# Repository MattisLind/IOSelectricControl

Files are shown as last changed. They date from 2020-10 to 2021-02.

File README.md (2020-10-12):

# IOSelectricControl
This project is to create a modern interface to an old IBM 731 IO Selectric terminal.

Back in the mid seventies my father bought a IO Selectric to use with his homebuilt computer. In order to connect it over serial line he had to build a small box with interface electronics. But he also did massive amounts of modifications to the 731 itself.

Top view. Quite a lot of dirt.

Top view when project started

Bottom view show all the modifications. There is even a power supply built into it

Bottom view

Unfortunately the documentation that covered what was done back then was scarce so I decvided to remove the modifications and get it back to a more original state. Instead of the control box full of TTL circuits and relays I decided to build a circuit based on a STM32 microcontroller to be able to have it to talk over USB.

## Links

* [Selectric I/O Reference Manual - Section 1](http://bitsavers.org/pdf/ibm/typewriter/selectric/241-5308_IO_SelectricRefMan.pdf)
* [Field Engineering Maintenance Manual Selectric ® I/O Keyboard Printer](http://bitsavers.org/pdf/ibm/typewriter/selectric/S225-1726-7_IOseleMnt_Nov70.pdf)

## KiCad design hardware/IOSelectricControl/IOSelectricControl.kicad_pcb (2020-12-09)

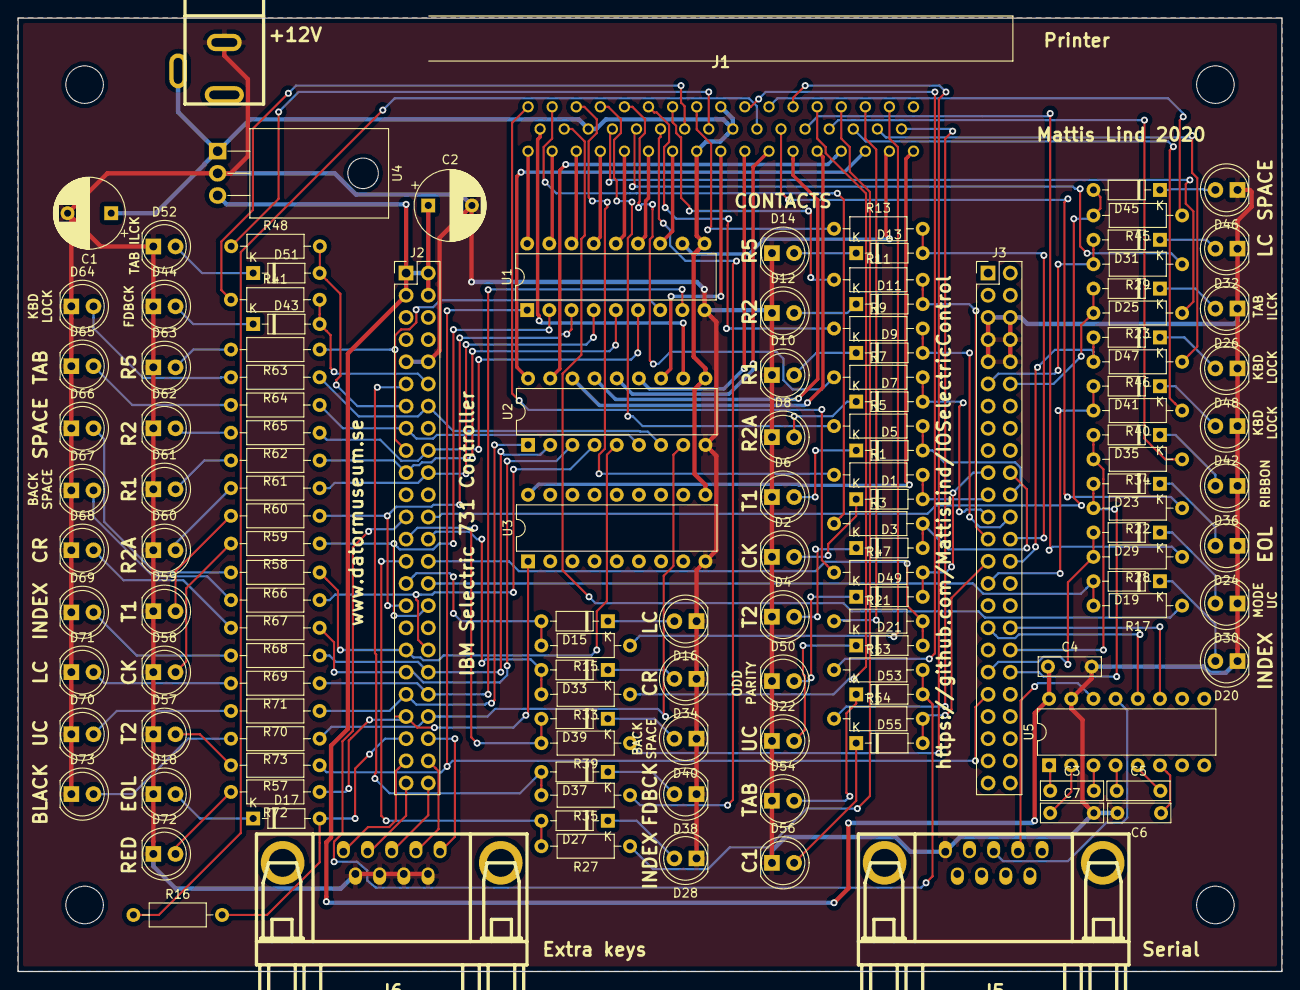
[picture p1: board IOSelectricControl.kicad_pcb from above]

Board: 2 copper layers, 144.8 x 109.2 mm, 136 parts (0 on the bottom side), 153 nets.

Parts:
C1: 47u; CP_Radial_D8.0mm_P5.00mm
C2: 100u; CP_Radial_D8.0mm_P5.00mm
C3, C4, C5, C6, C7: 0.1u; C_Rect_L7.0mm_W2.0mm_P5.00mm
D1, D3, D5, D7, D9, D11, D13, D15, D17, D19, D21, D23, D25, D27, D29, D31, D33, D35, D37, D39, D41, D43, D45, D47, D49, D51, D53, D55: 1N4148; D_DO-35_SOD27_P7.62mm_Horizontal
D2, D4, D6, D8, D10, D12, D14, D36, D50: YEL; LED_D5.0mm
D16, D22, D28, D34, D40, D46, D54: AMB; LED_D5.0mm
D18, D20, D26, D32, D44, D48: RED; LED_D5.0mm
D24, D30, D38, D42, D52, D56: GRN; LED_D5.0mm
D57, D58, D59, D60, D61, D62, D63: BLU; LED_D5.0mm
D64, D65, D66, D67, D68, D69, D70, D71, D72, D73: ORA; LED_D5.0mm
J1: DB-50; DD50S564TLF
J2, J3: HEADER_24x2; PinHeader_2x24_P2.54mm_Vertical
J4: +12V; dc_socket
J5: Serial; DB_9F
J6: Extra keys; DB_9F
R1, R3, R5, R7, R9, R11, R13, R15, R16, R17, R21, R22, R23, R27, R28, R29, R33, R34, R35, R39, R40, R41, R45, R46, R47, R48, R53, R54: 4,7k; R_Axial_DIN0207_L6.3mm_D2.5mm_P10.16mm_Horizontal
R57, R58, R59, R60, R61, R62, R63, R64, R65, R66, R67, R68, R69, R70, R71, R72, R73: 470; R_Axial_DIN0207_L6.3mm_D2.5mm_P10.16mm_Horizontal
U1, U2, U3: ULN2803A; DIP-18_W7.62mm
U4: L7805; TO-220-3_Horizontal_TabDown
U5: MAX202; DIP-16_W7.62mm

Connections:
+5V: C2.1, C4.1, J2.1, J2.2, J2.3, J2.4, U4.3, U5.16
+12V: C1.1, J1.8, J1.20, J1.26, J1.42, J4.1, U1.10, U2.10, U3.10, U4.1
/A: J1.1, U1.18
/AA: J1.44, R45.1
/B: J1.2, U1.17
/BB: J1.45, R39.1
/BREAK: J2.44, J6.1
/C: J1.3, U1.16
/CC: J1.46, R33.1
/CON_C1_NC: J1.19, R17.1
/CON_C1_NO: J1.33, R54.1
/CON_CK_NO: J1.36, R1.1
/CON_EOL_NC: J1.27, R16.1
/CON_EOL_NO: J1.28, R22.1
/CON_FDBCK_NC: J1.23, R35.1
/CON_FDBCK_NO: J1.24, R41.1
/CON_INDEX_NO: J1.47, R27.1
/CON_KBD_NC: J1.31, R40.1
/CON_KBD_NO: J1.32, R46.1
/CON_LC_NO: J1.49, R15.1
/CON_MODE_LC_NC: J1.22, R29.1
/CON_MODE_UC_NO: J1.29, R28.1
/CON_ODD_PARITY: J1.34, R47.1
/CON_R1_NO: J1.39, R9.1
/CON_R2A_NO: J1.38, R7.1
/CON_R2_NO: J1.40, R11.1
/CON_R5_NO: J1.41, R13.1
/CON_RIBBON_NO: J1.30, R34.1
/CON_T1_NO: J1.37, R5.1
/CON_T2_NO: J1.35, R3.1
/CON_TAB_ILCK_NC: J1.21, R23.1
/CON_TAB_ILCK_NO: J1.25, R48.1
/CON_TAB_NO: J1.43, R53.1
/CON_UC_NO: J1.48, R21.1
/CTRL: J2.46, J6.2
/D: J1.4, U1.15
/E: J1.5, U1.14
/EIA_RX: J5.3, U5.13
/EIA_TX: J5.2, U5.14
/F: J1.6, U1.13
/H: J1.7, U1.12
/K: J1.9, U2.12
/L: J1.10, U2.13
/M: J1.11, U2.14
/N: J1.12, U2.15
/P: J1.13, U2.16
/PAR0: J2.47, J6.4
/PAR1: J2.48, J6.3
/PARODD: J2.45, J6.5
/R: J1.14, U2.17
/S: J1.15, U2.18
/SER_RX: J3.33, U5.12
/SER_TX: J3.34, U5.11
/SOL_BLACK: J1.18, U2.11
/SOL_LC: J1.16, U1.11
/SOL_RED: J1.17, U3.18
/STM_BLACK: J2.42, R73.1, U2.8
/STM_BSP: J2.36, R67.1, U2.4
/STM_BSP_NO: D39.2, J2.25, R39.2
/STM_C1_NC: D19.2, J2.30, R17.2
/STM_C1_NO: D55.2, J3.27, R54.2
/STM_CK: J2.32, R58.1, U1.2
/STM_CK_NO: D1.2, J3.21, R1.2
/STM_CR: J2.37, R68.1, U2.3
/STM_CR_NO: D33.2, J2.26, R33.2
/STM_EOL_NC: D17.2, J2.43, R16.2
/STM_EOL_NO: D23.2, J3.38, R22.2
/STM_FDBCK_NC: D37.2, J2.11, R35.2
/STM_FDBCK_NO: D43.2, J2.12, R41.2
/STM_INDEX: J2.38, R69.1, U2.2
/STM_INDEX_NO: D27.2, J2.27, R27.2
/STM_KBD_LOCK: J2.14, R64.1, U2.7
/STM_KBD_NC: D41.2, J3.29, R40.2
/STM_KBD_NO: D47.2, J3.28, R46.2
/STM_LC: J2.40, R71.1, U1.8
/STM_LC_NO: D15.2, J2.29, R15.2
/STM_MODE_LC_NC: D31.2, J3.11, R29.2
/STM_MODE_UC_NO: D29.2, J3.37, R28.2
/STM_ODD_PAR_NO: D49.2, J3.19, R47.2
/STM_R1: J2.19, R61.1, U1.5
/STM_R1_NO: D9.2, J3.24, R9.2
/STM_R2: J2.18, R62.1, U1.6
/STM_R2A: J2.20, R60.1, U1.4
/STM_R2A_NO: D7.2, J3.23, R7.2
/STM_R2_NO: D11.2, J3.25, R11.2
/STM_R5: J2.17, R63.1, U1.7
/STM_R5_NO: D13.2, J3.26, R13.2
/STM_RED: J2.41, R72.1, U3.1
/STM_RIBBON_NO: D35.2, J3.36, R34.2
/STM_SP: J2.35, R66.1, U2.5
/STM_SP_NO: D45.2, J2.24, R45.2
/STM_T1: J2.31, R59.1, U1.3
/STM_T1_NO: D5.2, J3.22, R5.2
/STM_T2: J3.39, R57.1, U1.1
/STM_T2_NO: D3.2, J3.20, R3.2
/STM_TAB: J2.15, R65.1, U2.6
/STM_TAB_ILCK_NC: D25.2, J3.12, R23.2
/STM_TAB_ILCK_NO: D51.2, J2.13, R48.2
/STM_TAB_NO: D53.2, J2.23, R53.2
/STM_UC: J2.39, R70.1, U2.1
/STM_UC_NO: D21.2, J2.28, R21.2
GND: C1.2, C2.2, C4.2, C6.2, C7.2, D2.1, D4.1, D6.1, D8.1, D10.1, D12.1, D14.1, D16.1, D18.1, D20.1, D22.1, D24.1, D26.1, D28.1, D30.1, D32.1, D34.1, D36.1, D38.1, D40.1, D42.1, D44.1, D46.1, D48.1, D50.1, D52.1, D54.1, D56.1, D57.1, D58.1, D59.1, D60.1, D61.1, D62.1, D63.1, D64.1, D65.1, D66.1, D67.1, D68.1, D69.1, D70.1, D71.1, D72.1, D73.1, J2.9, J2.10, J3.5, J3.6, J3.7, J3.8, J3.9, J3.10, J4.2, J5.5, J6.6, J6.7, J6.8, J6.9, U1.9, U2.9, U3.9, U4.2, U5.15
unnamed: C3.1, U5.1
unnamed: C3.2, U5.3
unnamed: C5.1, U5.4
unnamed: C5.2, U5.5
unnamed: C6.1, U5.6
unnamed: C7.1, U5.2
unnamed: D1.1, D2.2
unnamed: D3.1, D4.2
unnamed: D5.1, D6.2
unnamed: D7.1, D8.2
unnamed: D9.1, D10.2
unnamed: D11.1, D12.2
unnamed: D13.1, D14.2
unnamed: D15.1, D16.2
unnamed: D17.1, D18.2
unnamed: D19.1, D20.2
unnamed: D21.1, D22.2
unnamed: D23.1, D24.2
unnamed: D25.1, D26.2
unnamed: D27.1, D28.2
unnamed: D29.1, D30.2
unnamed: D31.1, D32.2
unnamed: D33.1, D34.2
unnamed: D35.1, D36.2
unnamed: D37.1, D38.2
unnamed: D39.1, D40.2
unnamed: D41.1, D42.2
unnamed: D43.1, D44.2
unnamed: D45.1, D46.2
unnamed: D47.1, D48.2
unnamed: D49.1, D50.2
unnamed: D51.1, D52.2
unnamed: D53.1, D54.2
unnamed: D55.1, D56.2
unnamed: D57.2, R57.2
unnamed: D58.2, R58.2
unnamed: D59.2, R59.2
unnamed: D60.2, R60.2
unnamed: D61.2, R61.2
unnamed: D62.2, R62.2
unnamed: D63.2, R63.2
unnamed: D64.2, R64.2
unnamed: D65.2, R65.2
unnamed: D66.2, R66.2
unnamed: D67.2, R67.2
unnamed: D68.2, R68.2
unnamed: D69.2, R69.2
unnamed: D70.2, R70.2
unnamed: D71.2, R71.2
unnamed: D72.2, R72.2
unnamed: D73.2, R73.2

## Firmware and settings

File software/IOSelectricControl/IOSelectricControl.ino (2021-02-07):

/*
  IOSelectricControl

  STM32duino.com  Generic STMF103C Series  / STM32F103C8 20 k RAM 64 k flash ST-link

*/
#define CC_NUL 0
#define CC_R5  1 << 0
#define CC_R2  1 << 1
#define CC_R1  1 << 2
#define CC_R2A 1 << 3
#define CC_T1  1 << 4
#define CC_CK  1 << 5
#define CC_T2  1 << 6
#define CC_UC  1 << 7
#define CC_INDEX 1 << 8
#define CC_CR 1 << 9
#define CC_BSP 1 << 10
#define CC_SP  1 << 11
#define CC_TAB 1 << 12

int asciiToCorrespondanceCode [] = {
  CC_NUL,  // NUL
  CC_NUL,  // SOH
  CC_NUL,  // STX
  CC_NUL,  // ETX
  CC_NUL,  // EOT
  CC_NUL,  // ENQ
  CC_NUL,  // ACK
  CC_NUL,  // BEL
  CC_BSP,  // BS
  CC_TAB,  // TAB
  CC_INDEX,// LF
  CC_NUL,  // VT
  CC_NUL,  // FF
  CC_CR,   // CR
  CC_NUL,  // SO
  CC_NUL,  // SI
  CC_NUL,  // DLE
  CC_NUL,  // DC1
  CC_NUL,  // DC2
  CC_NUL,  // DC3
  CC_NUL,  // DC4
  CC_NUL,  // NAK
  CC_NUL,  // SYN
  CC_NUL,  // ETB
  CC_NUL,  // CAN
  CC_NUL,  // EM
  CC_NUL,  // SUB
  CC_NUL,  // ESC
  CC_NUL,  // FS
  CC_NUL,  // GS
  CC_NUL,  // RS
  CC_NUL,  // US
  CC_SP,   // SPACE
  CC_CK | CC_T1 | CC_R2A | CC_R1 | CC_R5, // !
  CC_UC | CC_T1 | CC_R2A | CC_R1,         // "
  CC_UC | CC_T2 | CC_T1  | CC_R2A | CC_R2 | CC_R5, // #
  CC_UC | CC_T2 | CC_CK  | CC_T1  | CC_R1 | CC_R5, // $
  CC_UC | CC_T2 | CC_CK  | CC_T1  | CC_R2A | CC_R1 | CC_R2, // %
  CC_UC | CC_T2 | CC_T1  | CC_R2A  | CC_R1 | CC_R5, // &
  CC_UC | CC_T2 | CC_CK | CC_T1 | CC_R2A | CC_R1 | CC_R2 | CC_R5, // '
  CC_UC | CC_T2 | CC_CK | CC_T1, // (
  CC_UC | CC_T2 | CC_T1 | CC_R1, // )
  CC_UC | CC_T2 | CC_CK | CC_T1 | CC_R2A | CC_R5, // *
  CC_UC | CC_CK | CC_R2A | CC_R2, // +
  CC_UC | CC_CK | CC_R2A | CC_R5, // ,
  CC_CK, // -
  CC_UC | CC_T1 | CC_R2A | CC_R2, // .
  CC_CK | CC_R1 | CC_R5, //  /
  CC_T2 | CC_T1 | CC_R1, // 0
  CC_T2 | CC_CK | CC_T1 | CC_R2A | CC_R1 | CC_R2 | CC_R5, // 1
  CC_T2 | CC_CK | CC_T1 | CC_R2A | CC_R2, // 2
  CC_T2 | CC_T1 | CC_R2A | CC_R2 | CC_R5, // 3
  CC_T2 | CC_CK | CC_T1 | CC_R1 | CC_R5, // 4
  CC_T2 | CC_CK | CC_T1 | CC_R2A | CC_R1, // 5
  CC_T2 | CC_T1 | CC_R2A, // 6
  CC_T2 | CC_T1 | CC_R2A | CC_R1 | CC_R5, // 7
  CC_T2 | CC_CK | CC_T1 | CC_R2A | CC_R5, // 8
  CC_T2 | CC_CK | CC_T1, // 9
  CC_UC | CC_R2A | CC_R1 | CC_R5, // :
  CC_R2A | CC_R1 | CC_R5, // ;
  CC_SP, // < - NA 
  CC_CK | CC_R2A | CC_R2,// = 
  CC_SP, // > - NA
  CC_UC | CC_CK | CC_R1 | CC_R5, // ?
  CC_UC | CC_T2 | CC_CK | CC_T1 | CC_R2A | CC_R2, // @
  CC_UC | CC_T1 | CC_R2A | CC_R5, // A
  CC_UC | CC_T2, // B
  CC_UC | CC_T2 | CC_R2A | CC_R5, // C
  CC_UC | CC_T2 | CC_CK | CC_R2A | CC_R1 | CC_R5, // D
  CC_UC | CC_T2 | CC_R2A | CC_R1, // E
  CC_UC | CC_R2A | CC_R2 | CC_R5, // F
  CC_UC | CC_CK | CC_R2A | CC_R1 | CC_R2 | CC_R5, // G
  CC_UC | CC_T2 | CC_CK | CC_R1, // H
  CC_UC | CC_CK | CC_T1 | CC_R2A, // I
  CC_UC | CC_R2A | CC_R1 | CC_R2, // J
  CC_UC | CC_T2 | CC_CK | CC_R2A,  // K
  CC_UC | CC_T2 | CC_R1 | CC_R5,// L
  CC_UC | CC_T1 | CC_R2A | CC_R1 | CC_R2 | CC_R5, // M
  CC_UC | CC_T2 | CC_R2A | CC_R2, // N
  CC_UC | CC_T1 | CC_R1 | CC_R5,// O
  CC_UC | CC_CK | CC_R2A | CC_R1, // P
  CC_UC | CC_R2A,  // Q
  CC_UC | CC_CK | CC_T1 | CC_R2A | CC_R1 | CC_R5, // R
  CC_UC | CC_CK | CC_T1 | CC_R1, // S
  CC_UC | CC_T2 | CC_CK | CC_R2A | CC_R1 | CC_R2, // T
  CC_UC | CC_T2 | CC_CK | CC_R2A | CC_R2 | CC_R5, // U
  CC_UC | CC_CK | CC_T1 | CC_R2A | CC_R2 | CC_R5, // V
  CC_UC | CC_T1, // W
  CC_UC | CC_T2 | CC_R2A | CC_R1 | CC_R2 | CC_R5, // X
  CC_UC | CC_R1, // Y
  CC_UC | CC_T2 | CC_T1 | CC_R2A | CC_R1 | CC_R2, // Z
  CC_UC | CC_T2 | CC_CK | CC_T1 | CC_R2A | CC_R1 | CC_R2 | CC_R5, // [ 
  CC_SP, // \ - NA
  CC_T2 | CC_CK | CC_T1 | CC_R2A | CC_R1 | CC_R2 | CC_R5,// ]
  CC_SP, // ^ -NA
  CC_UC | CC_CK, // _
  CC_SP, // ` -NA
  CC_T1 | CC_R2A | CC_R5, // a
  CC_T2, // b
  CC_T2 | CC_R2A | CC_R5, // c
  CC_T2 | CC_CK | CC_R2A | CC_R1 | CC_R5, // d
  CC_T2 | CC_R2A | CC_R1, // e
  CC_R2A | CC_R2 | CC_R5, // f
  CC_CK | CC_R2A | CC_R1 | CC_R2 | CC_R5, // g
  CC_T2 | CC_CK | CC_R1, // h
  CC_CK | CC_T1 | CC_R2A, // i
  CC_R2A | CC_R1 | CC_R2, // j
  CC_T2 | CC_CK | CC_R2A,  // k
  CC_T2 | CC_R1 | CC_R5,// l
  CC_T1 | CC_R2A | CC_R1 | CC_R2 | CC_R5, // m
  CC_T2 | CC_R2A | CC_R2, // n
  CC_T1 | CC_R1 | CC_R5,// o
  CC_CK | CC_R2A | CC_R1, // p
  CC_R2A,  // q
  CC_CK | CC_T1 | CC_R2A | CC_R1 | CC_R5, // r
  CC_CK | CC_T1 | CC_R1, // s
  CC_T2 | CC_CK | CC_R2A | CC_R1 | CC_R2, // t
  CC_T2 | CC_CK | CC_R2A | CC_R2 | CC_R5, // u
  CC_CK | CC_T1 | CC_R2A | CC_R2 | CC_R5, // v
  CC_T1, // w
  CC_T2 | CC_R2A | CC_R1 | CC_R2 | CC_R5, // x
  CC_R1, // y
  CC_T2 | CC_T1 | CC_R2A | CC_R1 | CC_R2, // z
  CC_SP, // { - NA
  CC_SP, // | - NA
  CC_SP, // } - NA
  CC_SP, // ~ - NA
  CC_NUL// DEL - NA 
  };

#define SHIFT_UC 1
#define SHIFT_LC 0
#define FDBCK_NC PE2
#define FDBCK_NO PE3
#define TAB_ILCK_NO PE4
#define SOL_KBD_LOCK PE5
#define SOL_TAB PE6
#define SOL_R5 PC0
#define SOL_R2 PC1
#define SOL_R1 PC2
#define SOL_R2A PC3
#define TAB_NO PA0
#define SP_NO PA1
#define BSP_NO PA2
#define CR_NO PA3
#define INDEX_NO PA4
#define UC_NO PA5
#define LC_NO PA6
#define C1_NC PA7
#define SOL_T1 PC4
#define SOL_CK PC5
#define SOL_SP PE7
#define SOL_BSP PE8
#define SOL_CR PE9
#define SOL_INDEX PE10
#define SOL_UC PE11
#define SOL_LC PE12
#define SOL_RED PE13
#define SOL_BLACK PE14
#define EOL_NC PE15
#define MODE_LC_NC PE1
#define TAB_ILCK_NC PE0
#define ODD_PARITY_NO PD7
#define T2_NO PD6
#define CK_NO PD5
#define T1_NO PD4
#define R2A_NO PD3
#define R1_NO PD2
#define R2_NO PD1
#define R5_NO PD0
#define C1_NO PC12
#define KBD_NC PC10
#define KBD_NO PC11
#define RIBBON_NO PC9
#define MODE_UC_NO PC8
#define EOL_NO PC7
#define SOL_T2 PC6

int shiftState; 



// the setup function runs once when you press reset or power the board
void setup() {
  // initialize digital pin LED_BUILTIN as an output.
  pinMode(FDBCK_NC, INPUT_PULLDOWN); 
  pinMode(FDBCK_NO, INPUT_PULLDOWN); 
  pinMode(TAB_ILCK_NO, INPUT_PULLDOWN);
  digitalWrite(SOL_KBD_LOCK, LOW);
  pinMode(SOL_KBD_LOCK, OUTPUT);
  digitalWrite(SOL_TAB, LOW);
  pinMode(SOL_TAB, OUTPUT); 
  digitalWrite(SOL_R5, LOW);
  pinMode(SOL_R5, OUTPUT); 
  digitalWrite(SOL_R2, LOW);
  pinMode(SOL_R2, OUTPUT);
  digitalWrite(SOL_R1, LOW); 
  pinMode(SOL_R1, OUTPUT);
  digitalWrite(SOL_R2A, LOW);
  pinMode(SOL_R2A, OUTPUT);
  pinMode(TAB_NO, INPUT_PULLDOWN);
  pinMode(SP_NO, INPUT_PULLDOWN);
  pinMode(BSP_NO, INPUT_PULLDOWN);  
  pinMode(CR_NO, INPUT_PULLDOWN);  
  pinMode(INDEX_NO, INPUT_PULLDOWN); 
  pinMode(UC_NO, INPUT_PULLDOWN); 
  pinMode(LC_NO, INPUT_PULLDOWN);
  pinMode(C1_NC, INPUT_PULLDOWN);
  digitalWrite(SOL_T1, LOW);
  pinMode(SOL_T1, OUTPUT);
  digitalWrite(SOL_CK, LOW);
  pinMode(SOL_CK, OUTPUT);
  digitalWrite(SOL_SP, LOW);
  pinMode(SOL_SP, OUTPUT);  
  digitalWrite(SOL_BSP, LOW);
  pinMode(SOL_BSP, OUTPUT);  
  digitalWrite(SOL_CR, LOW);
  pinMode(SOL_CR, OUTPUT); 
  digitalWrite(SOL_INDEX, LOW);
  pinMode(SOL_INDEX, OUTPUT);
  digitalWrite(SOL_UC, LOW);
  pinMode(SOL_UC, OUTPUT);  
  digitalWrite(SOL_LC, LOW);
  pinMode(SOL_LC, OUTPUT);  
  digitalWrite(SOL_RED, LOW);
  pinMode(SOL_RED, OUTPUT); 
  digitalWrite(SOL_BLACK, LOW);
  pinMode(SOL_BLACK, OUTPUT); 
  pinMode(EOL_NC, INPUT_PULLDOWN);
  pinMode(MODE_LC_NC, INPUT_PULLDOWN);
  pinMode(TAB_ILCK_NC, INPUT_PULLDOWN);  
  pinMode(ODD_PARITY_NO, INPUT_PULLDOWN);  
  pinMode(T2_NO, INPUT_PULLDOWN); 
  pinMode(CK_NO, INPUT_PULLDOWN); 
  pinMode(T1_NO, INPUT_PULLDOWN);
  pinMode(R2A_NO, INPUT_PULLDOWN);
  pinMode(R1_NO, INPUT_PULLDOWN); 
  pinMode(R2_NO, INPUT_PULLDOWN); 
  pinMode(R5_NO, INPUT_PULLDOWN);
  pinMode(C1_NO, INPUT_PULLDOWN);
  pinMode(KBD_NO, INPUT_PULLDOWN);
  digitalWrite(KBD_NO, LOW);
  pinMode(KBD_NC, INPUT_PULLDOWN); 
  digitalWrite(KBD_NC, LOW);
  pinMode(RIBBON_NO, INPUT_PULLDOWN);
  digitalWrite(RIBBON_NO, LOW); 
  pinMode(MODE_UC_NO, INPUT_PULLDOWN);
  digitalWrite(MODE_UC_NO, LOW);
  pinMode(EOL_NO, INPUT_PULLDOWN);
  digitalWrite(EOL_NO, LOW);
  digitalWrite(SOL_T2, LOW);
  pinMode(SOL_T2, OUTPUT);
  Serial.begin(9600);
  Serial.write("SELECTRIC> ");
}

/*
 * M PB6  SPACE
 * P PB7  CR
 * T PB8  SHIFT LOWER CASE
 * R PB5  INDEX
 * S PB4  SHIFT UPPER CASE
 */









bool energizeSelectionSolenoids (int val) {
  bool ret = false;
  if (val & CC_T2) { 
    digitalWrite (SOL_T2, HIGH);
    ret = true;
  } 
  if (val & CC_CK) { 
    digitalWrite (SOL_CK, HIGH);
    ret = true;
  } 
  if (val & CC_T1) { 
    digitalWrite (SOL_T1, HIGH);
    ret = true;
  } 
  if (val & CC_R2A) { 
    digitalWrite (SOL_R2A, HIGH);
    ret = true;
  } 
  if (val & CC_R1) { 
    digitalWrite (SOL_R1, HIGH);
    ret = true;
  } 
  if (val & CC_R2) { 
    digitalWrite (SOL_R2, HIGH);
    ret = true;
  } 
  if (val & CC_R5) { 
    digitalWrite (SOL_R5, HIGH);
    ret = true;
  } 
  return ret;
}

void deEnergizeAllSolenoids() {
    digitalWrite (SOL_T2, LOW);
    digitalWrite (SOL_CK, LOW);
    digitalWrite (SOL_T1, LOW);
    digitalWrite (SOL_R2A, LOW);
    digitalWrite (SOL_R1, LOW);
    digitalWrite (SOL_R2, LOW);
    digitalWrite (SOL_R5, LOW);
    digitalWrite (SOL_UC, LOW);
    digitalWrite (SOL_LC, LOW);
    digitalWrite (SOL_SP, LOW);
    digitalWrite (SOL_CR, LOW);
    digitalWrite (SOL_TAB, LOW);
    digitalWrite (SOL_BSP, LOW);
    digitalWrite (SOL_INDEX, LOW);
}


bool energizeShiftSolenoids(int val) {
  Serial.println(val,HEX);
  if (val & CC_UC) { // We need to go to UpperCase
    Serial.println(digitalRead(MODE_LC_NC));
    if (HIGH == (digitalRead(MODE_LC_NC))) { // but currently we are in lower case
      digitalWrite (SOL_UC, HIGH); // start moving to uppercase
      return true;
    }
  } else { // We need to go to Lower Case
    Serial.println(digitalRead(MODE_UC_NO));
    if (HIGH == (digitalRead(MODE_UC_NO))) { // but we are in upper case
      digitalWrite (SOL_LC, HIGH); // energize lower case solenoid.
      return true;
    }
  }
  return false;
}


bool energizeCRSolenoid(int val) {
  if (val & CC_CR) {
    digitalWrite (SOL_CR, HIGH);
    return true;
  }
  return false;
}

bool energizeSpaceSolenoid(int val) {
  if (val & CC_SP) {
    digitalWrite (SOL_SP, HIGH);
    return true;
  }
  return false;
}



bool energizeIndexSolenoid(int val) {
  if (val & CC_INDEX) {
    digitalWrite (SOL_INDEX, HIGH);
    return true;
  }
  return false;
}


bool isReady() {
  return digitalRead(FDBCK_NC)==HIGH;
}

bool isBusy() {
  return digitalRead(FDBCK_NO)==HIGH;
}

void waitForFeedback() {
  while (isReady()); // Wait until we go busy then we turn of solenoids
  deEnergizeAllSolenoids();
  while (!isReady()); // Wait until we get ready again.  
}


#define TAB 9
#define CR 13
#define SP 32
#define INDEX 10
#define BSP 8

int getFunctionCode () {
  // Test TAB, CR, BS, INDEX or SP to see if any of those has been pressed
  if (digitalRead(INDEX_NO) == 1) {
    Serial.println("INDEX"); 
    return INDEX;  
  } 
  if (digitalRead(CR_NO) == 1) {
    Serial.println("CR"); 
    return CR;  
  }
  if (digitalRead(BSP_NO) == 1) {
    Serial.println("BSP"); 
    return BSP;  
  }
  if (digitalRead(TAB_NO) == 1) {
    Serial.println("TAB"); 
    return TAB;  
  }
  if (digitalRead(SP_NO) == 1) {
    Serial.println("SP"); 
    return SP;  
  }
  return 0;
}



// the loop function runs over and over again forever
void loop() {
  bool busy;
  char tmp;
  int val;
  if (isBusy()) {
    delay (1);
    if (isBusy()) {
      if ((val = getFunctionCode()) != 0) {
         Serial.write(val); 
         while (isBusy());
         if ((val == TAB) || (val == CR)) {
           while(digitalRead(TAB_ILCK_NO)==1);  // Wait until CR or TAB is completed. 
         }
      } else {
        // The feedback signal was due to a normal letter or digit was pressed
        if (digitalRead(C1_NO)==1) {
          delay(1);
          if (digitalRead(C1_NO)==1) { 
            // Sample selection contacts 
            val = (digitalRead(R5_NO)? CC_R5:0);
            Serial.print(val,HEX);
            Serial.print(" ");
            val |= (digitalRead(R2_NO)?CC_R2:0);
            Serial.print(val,HEX);
            Serial.print(" ");
            val |= (digitalRead(R1_NO)?CC_R1:0);
            Serial.print(val,HEX);
            Serial.print(" ");
            val |= (digitalRead(R2A_NO)?CC_R2A:0);
            Serial.print(val,HEX);
            Serial.print(" ");
            val |= (digitalRead(T1_NO)?CC_T1:0);
            Serial.print(val,HEX);
            Serial.print(" ");
            val |= (digitalRead(CK_NO)?CC_CK:0);
            Serial.print(val,HEX); 
            Serial.print(" ");
            val |= (digitalRead(T2_NO)?CC_T2:0);
            while (isBusy());
            Serial.println(val,HEX);
          } else {
            return; // Just a glitch.
          }  
        }
      }
    } else {
      return; // This was just a glicth
    }
  }
  if (Serial.available()> 0) {
    tmp = Serial.read();
    val = asciiToCorrespondanceCode[tmp & 0x7f];
    busy = energizeShiftSolenoids(val);
    if (busy) waitForFeedback();
    busy = energizeSelectionSolenoids (val);
    if (busy) waitForFeedback();
  }
}

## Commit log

2020-10-11 Added methods to energize solenoids
2020-10-11 First attempt to print a line of text.
2020-10-13 Added printing a line at once.
2020-10-17 Fixing 1 and c characters.
    [IOSelectricControl.ino]
2020-12-09 Added Kicad files.
    [IOSelectricControl-B.Cu.gbr, IOSelectricControl-B.Mask.gbr, IOSelectricControl-B.SilkS.gbr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]
2021-02-07 Last commit before the catastrophic failure of my nice little 731. I might never get back to this project :-(
    [IOSelectricControl.ino]
